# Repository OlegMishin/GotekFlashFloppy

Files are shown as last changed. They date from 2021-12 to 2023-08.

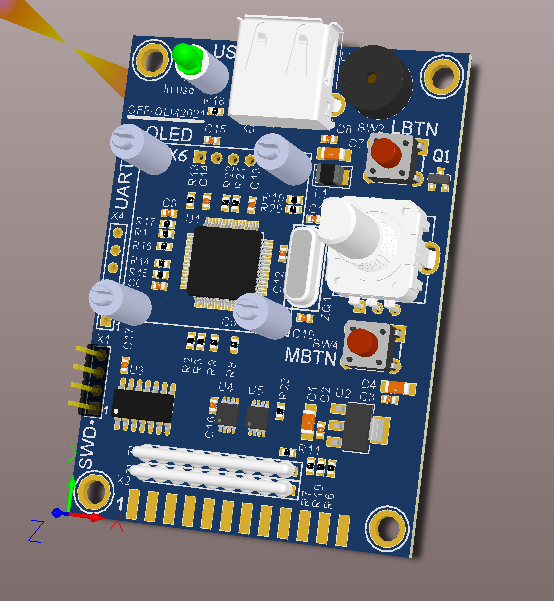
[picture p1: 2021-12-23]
gff-3D-render.png

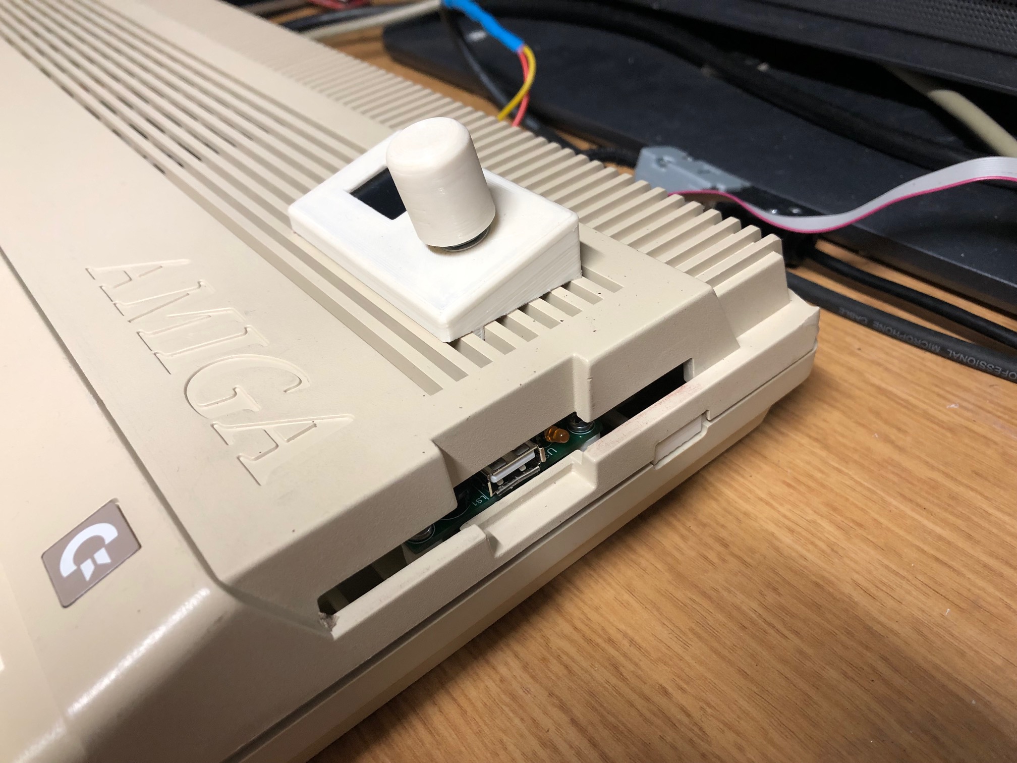
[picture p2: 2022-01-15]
A500_mount_example1.jpg

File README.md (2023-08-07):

# GotekFlashFloppy

A Gotek based PCB for Amiga computer. Can be mounted externally and internally.
Can be equipped with push buttons or with a rotary encoder. A 0.96" OLED display can be directly mounted using 4 spacers. I use 0.96 128x64 OLED (25.3x26.1mm overall dimensions) which is available in various online stores.

A 23-pin connector can be directly soldered to the pcb. Also, with an adapter pcb (23 to 34 pin) it can be mounted internally as "classic" Gotek pcb. 
Adapter's Gerbers located in **"gff_int_adapter_rev0.zip"** archive.

## Building

The BOM provided to build the drive as an external. Drive select configured as Drive 1 (selectable via R6/R7/R10).
The enclosure STL files also provided in "Cad\external case" location.
U4/U5 and the buttons unmounted. 
For louder movement sound I would recommend to use a MOSFET (e.g. IRLML2803 etc) instead of the BJT due to lower voltage drop.

## Firmware: 

Please refer to FlashFloppy's repository for the latest one: https://github.com/keirf/FlashFloppy

## MPU programming

Some early revisions of the MPU it can not be programmed via DFU. It is described in an application note AN2606(chapter 16.3.2):
https://www.st.com/resource/en/application_note/cd00167594-stm32-microcontroller-system-memory-boot-mode-stmicroelectronics.pdf

As I have such early revision of the MPU, I needed to use SWD interface. Actually, DFU mode flashing was not considered in the design. Related jumpers will be added in the next pcb revision.

Hardware: ST-LINK V2 (Chinese clone).
The MPU supplied from ST-LINK. It is enough for programming.



Software(Windows): STM32 ST-LINK Utility. Can be downloaded here: https://www.st.com/en/development-tools/stsw-link004.html

One important note to the ST-LINK flashing method. The following steps might be required if the MPU already programmed:
1. Run the tool, select "Connect under RESET" in settings. 
2. Connect ST-Link (it provides 3.3V which is enough for the MPU programming). 
3. Short C9 (to activate RESET)
4. Press "Connect" button, 
5. Release RESET
6. Open "hex" file and program it pressing "Program Verify" button.



Other HW tools can be used for the MPU programming:

- FT2232H based with OpenOCD. Very easy to build.
- J-LINK
- U-LINK

## PCB:

Two layers, 1.6mm thikness. Optimized for JLCpcb.

3D render of the pcb(Just a nice picture. Some components must be unpopulated):

изображение

Adapter board(soldered side by side to the main pcb):

изображение

## An example of internal mount with a 3D printed frame
Adapter's (frame) STL model is in CAD folder.

изображение

The display and rotary encoder mounted on top of the Amiga 500. Its model also in the "Cad" folder.
изображение

## As an external floppy
3D render.

изображение

The device in 3D printed enclosure. Connected to my Amiga 500
изображение

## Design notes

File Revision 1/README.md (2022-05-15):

# Revision 1

Changes list

- Removed U4/U5
- Updated Programming jumpers and related silcscreen
- Added +5V header to supply the board for MPU programming
- Added "Drive select" DIP switch. It planned to be accessible via an opening in an external enclosure
- PC mode (Jumper-C) is selectable via DIP switch

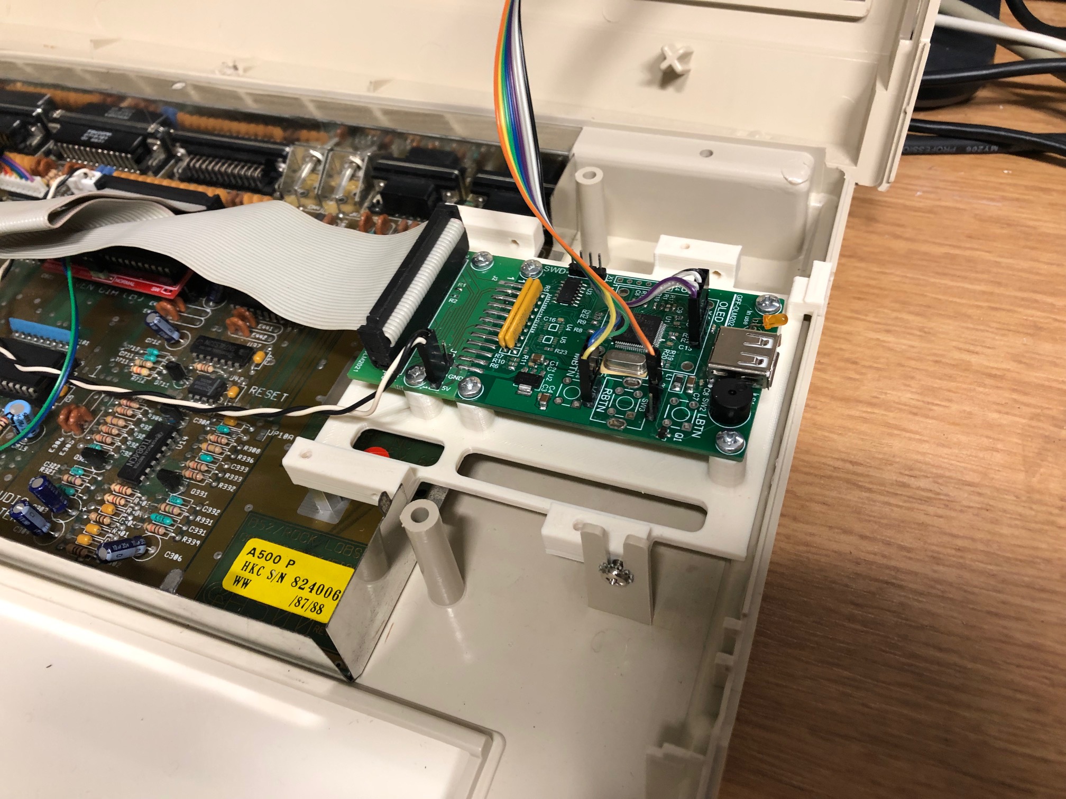
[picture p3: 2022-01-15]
A500_mount_example2.jpg

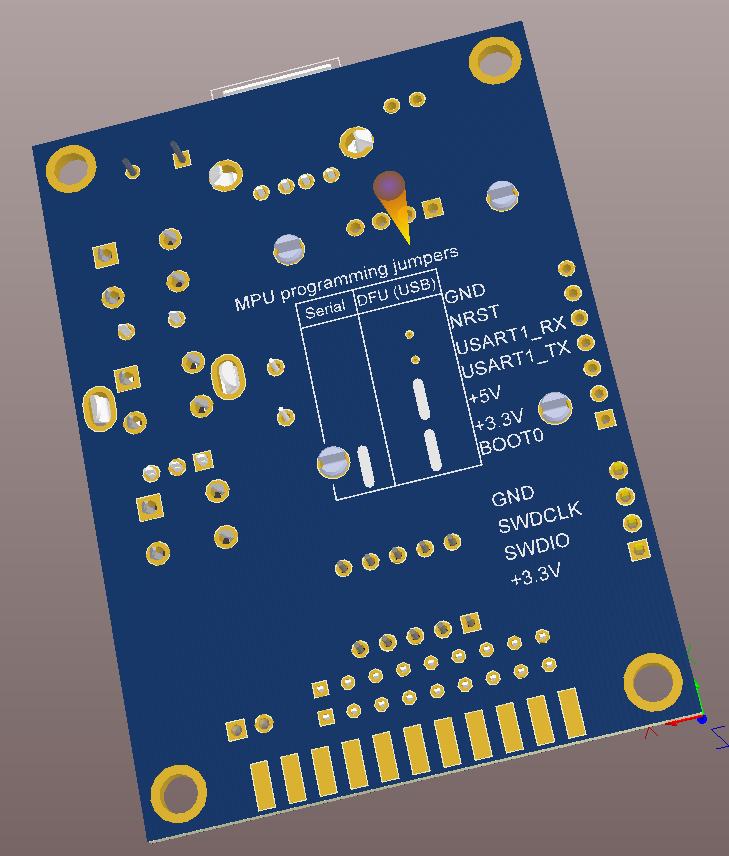
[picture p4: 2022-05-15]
Revision 1/3D_render_bot.png

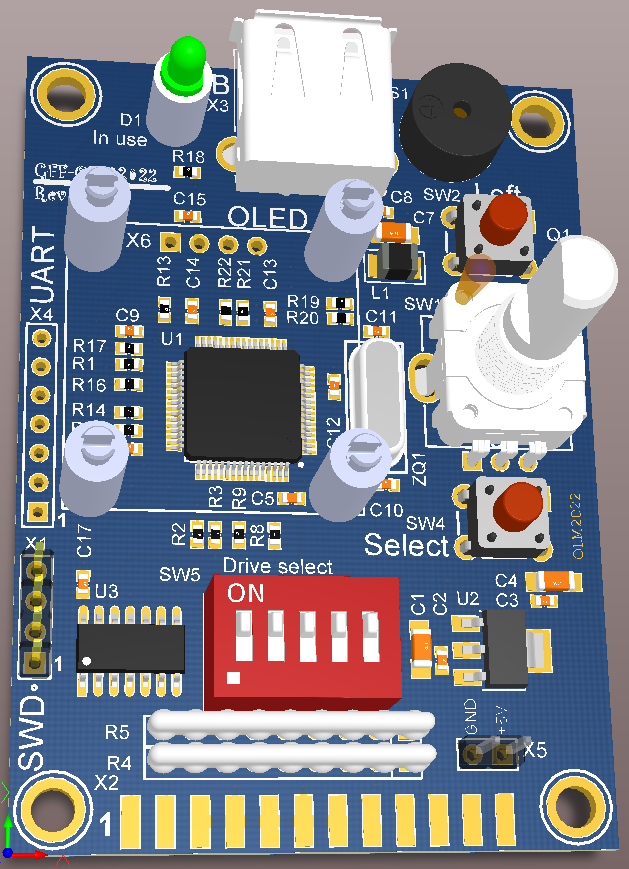
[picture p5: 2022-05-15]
Revision 1/3D_render_top.png

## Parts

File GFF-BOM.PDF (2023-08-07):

Designator | Quantity | Part | Description | Manufacturer | Comment | Value
C1, C4, C7 | 3 | C1206C106K4RACTU | Ceramic capacitor SMD | Kemet | Capacitor | 10uF
C2, C3, C5, C6, C8, C9, C12, C13, C14, C15, C16, C17 | 12 | CL10B104KB8NNNL | Ceramic capacitor SMD | Samsung | Capacitor | 100nF
C10, C11 | 2 | CC0603JPNPO9BN220 | Ceramic capacitor SMD | Yageo | Capacitor | 22pF
D1 | 1 | LED 3mm Orange | LED d3mm | | LED | d=3mm, Orange
H1 | 1 | 0.96 OLED I2C 25.3x26.1mm | 0.96 OLED display | | OLED display | 0.96 OLED I2C 25.3x26.1mm
L1 | 1 | BLM31PG601SN1L | Ferrite bead | Bourns | Ferrite bead | 600R @100MHz
LS1 | 1 | GT-0905A | 4-6V small buzzer (9mm) | Soberton | Buzzer passive | GT-0905A
Q1 | 1 | Alternative IRLML2803 | NPN Resistor-equipped Transistor | | Transistor | PDTC114ET
R1, R2, R3 | 3 | 10k 5% 0603 | Resistor SMD | | Resistor | 10K
R4, R5 | 2 | 4609X-101-102LF | SIP bussed resistor network. 8 resistors | Bourns | Resistor network | 1K x 8
R6, R8, R9, R16, R20, R21 | 6 | 0R 5% 0603 | Resistor SMD | | Resistor | 0R
R13 | 1 | 4.7k 5% 0603 | Resistor SMD | | Resistor | 4.7K
R14, R15 | 2 | 22R 5% 0603 | Resistor SMD | | Resistor | 22
R18 | 1 | 1k 5% 0603 | Resistor SMD | | Resistor | 1K
SW1 | 1 | PEC11R-4020K-S0024 | Rotary encoder with a switch | Bourns | Rotary encoder | PEC11R-4020K-S0024
U1 | 1 | STM32F105RBT6 | ST MCU with CAN and USB | ST Micro | Microcontroller | STM32F105RBT6
U2 | 1 | REG1117-3.3 | 800mA LDO Regulator | Texas Instruments | LDO | REG1117-3.3
U3 | 1 | SN74LS07DRE4 | Hex Buffer (Open Drain) | Texas Instruments | IC | SN74LS07DRE4
X1 | 1 | 5-146285-4 | SWD connector | TE Connectivity | Connector | PLS-4
X2 | 1 | DB-23 Male | Amiga external floppy connector. 23 pin Male. | | Connector | DB-23 Male
X3 | 1 | 292303-5 | Conn USB 2.0 Type A | TE Connectivity | Connector | 292303-5
X4 | 1 | 5-146285-6 | Header, 6-Pin | TE Connectivity | Connector | PLS-6
X6 | 1 | 801-87-004-10-001101 | Female Header, 4-Pin | Preci-Dip | Connector | BLS-4
ZQ1 | 1 | HC-49/U-S8000000ABJB | Crystal | Citizen Finedevice CCR YSTAL | | 8MHz

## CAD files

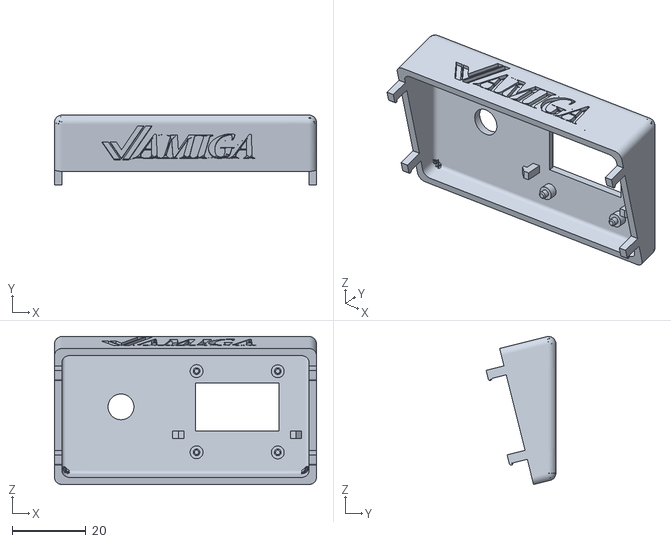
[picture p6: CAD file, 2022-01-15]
Cad/A500_rotary_128x64_oled_v20.STL
71.0 x 18.9 x 40.1

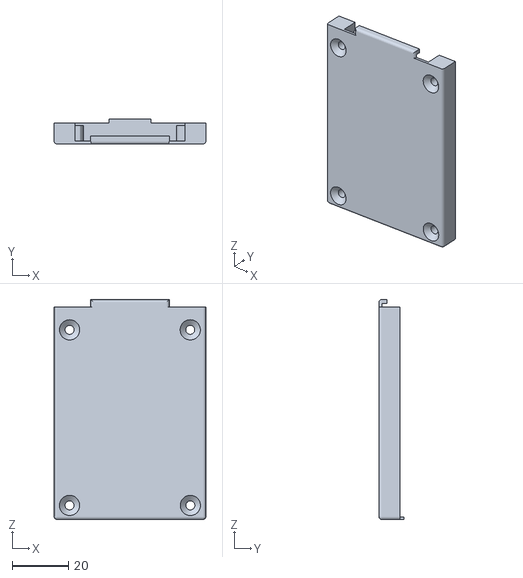
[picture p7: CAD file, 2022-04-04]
Cad/external case/Case_bottom.STL
54.0 x 8.90 x 78.3

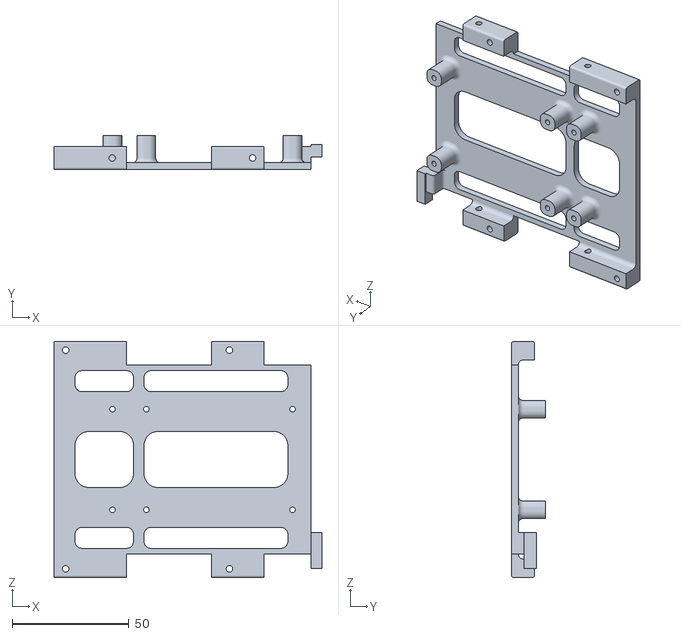
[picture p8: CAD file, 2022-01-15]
Cad/A500_internal_mount_v2.STL
114.6 x 14.7 x 101.0

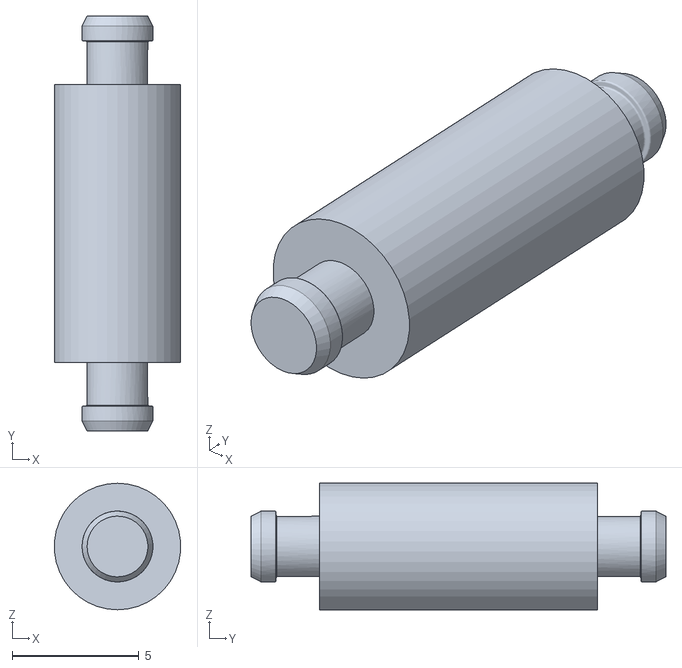
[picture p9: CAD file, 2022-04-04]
Cad/external case/Spacer_OLED.STL
4.98 x 16.4 x 5.00

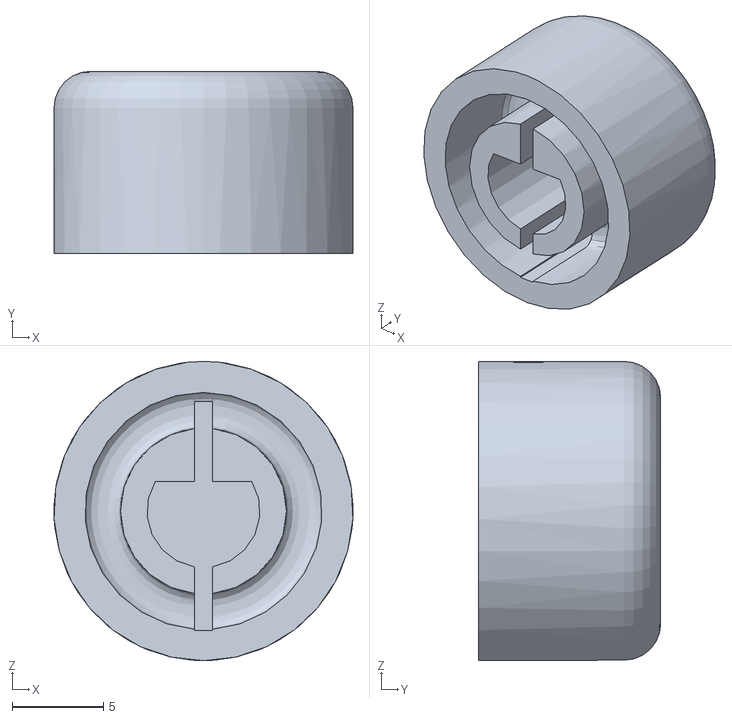
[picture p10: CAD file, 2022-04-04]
Cad/external case/A500_rotary_knob_H9.STL
16.4 x 10.0 x 16.4

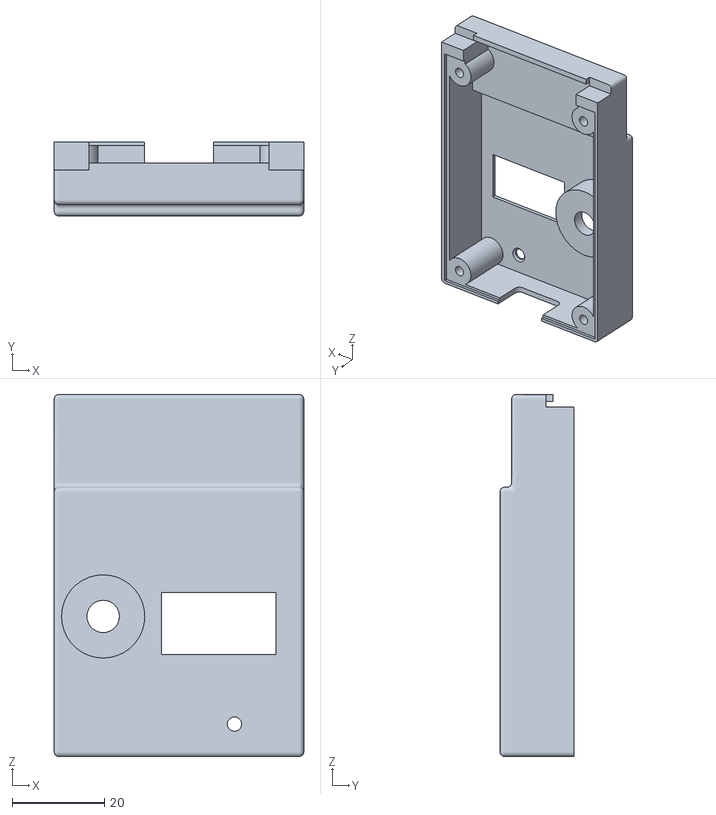
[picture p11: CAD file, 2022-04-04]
Cad/external case/Case_top.STL
54.0 x 16.0 x 78.3

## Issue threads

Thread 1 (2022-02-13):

BOM missing u4/u5

thbreidenbach, 2022-02-13:
Hey, wondered if missing u4/u5 is on purpose for maybe another hardware revision. I ordered them from the Schematics but since there's no design files it's also a bit hard to always find the right footprints for ICs. Maybe you could either give access to design files or add more information to the BOM.
Great work anyways!! Ordered 3 PCB and will give feedback!!

OlegMishin, 2022-02-13:
Hi,
U4/U5 are optional components to implement Amiga's external drive circuit(I've updated the schematics with such comment). As FlashFloppy supports this feature in firmware, U4/U5 are not needed. The  ICs and other components which shall be not mounted marked as DNP on the schematics.
Please follow the BOM for components ordering and assembly.

Thanks for your feedback!

BR
Oleg

Closed 2022-04-09.

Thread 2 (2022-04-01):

First populated Board not working

thbreidenbach, 2022-04-01:
Checked the board the whole day, no sign of life.
For programming you might consider making 5V accessible on e.g. the uart connector. For USB/serial programming access to 5V is necessary so placing it next to tx would be beneficial.
That said, also debug led might be handy when checking the board.

How did you program the board initially? Is there some clue since UART and USB give no response.
For UART I used 5V from the Drive Connector and connected rx/tx and vice versa and a jumper from Boot0 to 3.3V. No life..
For USB I connected TX/5V and Boot0/3.3V. No connection/Hardware detection possible.

Another question with regards to r4/r5: Are those networks bussed or star?

I'll add some Photos, maybe you can spot an error. For differing footprints I measured for connection. All fine
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
.

Thanks in Advance!!

Yours Thorsten

OlegMishin, 2022-04-02:
Hello Thorsten,

Thank you for building my board. The soldering looks very nice. I see no errors.
Regarding the MPU's programming. I program it via SWD interface (as you see, there is X1 connector mounted). I use ST-LINK v2 (cheap Chinese clone) debugger and STM32 ST-LINK Utility SW. Let me update "read.me" file with the short instruction.

Just checked my boards, the DFU mode did not work for me. There is an Errata item in MPU's datasheet, looks like it not possible for earlier releases of the MPU:
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
My MPU has "043" date code. Seems this is a problem. If I see correctly, on your MPU the date code starts from 4 - the same issue.

Regarding R4/R5 they are bussed according to Bourns description:
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
Please refer to the board's schematics:
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

Hope my answers help :)

Regards
Oleg

thbreidenbach, 2022-04-02:

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

OlegMishin, 2022-04-02:
Thanks for the feedback. The items go to a TODO list.
I have a question about Drive Select. As the selection already implemented via solder-jumpers R6/R7/R10 as on the below picture, do you mean it would be better to have normal jumpers instead?
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

thbreidenbach, 2022-04-02:
Hi, indeed solder jumpers are not ideal for an external drive which might easily be used in different systems. Indicator led would be fancy.

Yours
Thorsten

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

OlegMishin, 2022-04-04:
Hi,
Ok, I will consider at least jumpers or a DIP switch. So it would be possible to change the drive number and see the current configuration without opening the case. I will also update 3D model of the external case.

Regards
Oleg

thbreidenbach, 2022-04-04:
Perfect! Are files for the external case up yet? Would 5V be possible next to TX for chip revisions that offer usb programming? For uart 5V supply is also mandatory and unavailable as of yet. (Labels/Silkscreen would be important)
Yours
Thorsten

Von meinem iPhone gesendet

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

thbreidenbach, 2022-05-14:
Hey Oleg, I’m about to order several PCB. Have you had the opportunity to offer some production files? If possible I’ll test as soon as possible. The design looks extremely well.

There was one thing that came to my mind. I use a PC Bridgeboard which needs the JC jumper be set. Since the goldengate provides a db25 con that would be nice.

Hope you’re doing well, your Gotek still works like a charm! Thank you!

Thorsten

OlegMishin, 2022-05-15:
Hi Thorsten,

I'm doing well, thanks. Hope you too.

I'm happy the device is working well for you. Initially it was designed for Amiga use only, but recently I bought an old PC mainboard and started to play with DOS stuff, so it was very useful in a PC mode too. Due to this I added a JC to the DIP switch.
If the design looks ok for you, you can build it using the gerbers I put in "Release 1\gerbers" folder. DRC completed without any issues, so it is safe to build.

I didn't get you point regarding db25, what do you mean? Is it about some other computer connection, other than Amiga/PC?

BR
Oleg

thbreidenbach, 2022-05-15:
Hey Oleg, great News! Will order a bunch of ten immediately.

My point was that the Bridgeboard utilizes the same connection than the Amiga, so it’s an even greater addon with a jc jumper. Some PC Cards have a different external connector I believe and would need different interface. But this fits as is. This way I can use the internal Gotek in my Amiga 4000 as an Amiga Drive. Your board is perfectly fitted for my Big Box Amiga with Bridgeboard!

yours
Thorsten

Closed 2025-07-10.

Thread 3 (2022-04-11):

Need a fully assembled PCB

danko79, 2022-04-11:
Hi Oleg, i'm Juri from Italy, i find your project and really interesting, would you have an assembled PCB for sale?
sorry but i didn't know how to contact you.
Regards

OlegMishin, 2022-04-11:
Hi Juri, nice to meet you.

Sorry, I don't have assembled pcb for sale. At least for the revision 0. There are some upcoming changes towards revision 1, I'm going order some pcbs for testing and some of them perhaps will be available for sale. I will update the project's information here when it is ready but can not promise it will be soon.
Could you please have a look at the "Revision 1" files and let me know if you have any coments.

Thanks!

Regards
Oleg

Closed 2022-04-24.

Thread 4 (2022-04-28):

R1 & R2 internal connector PCB

drwhy75, 2022-04-28:
Hi !
Nice work !!
I am trying to build one of your Rev0 boards but I am not able to find the values for the Resistors R1 & R2 on the little
internal connector PCB. (could not find / or see them in the BoM).

So far I have finished soldering all components (without R1 & R1 & the buzzer).
... will try to flash the FW when all soldering is finished.

Cheerz

OlegMishin, 2022-04-28:
Hi!
Thanks! The resistors in fact are jumpers for drive selection. As you can see on the adaptor's schematics, R1 is 0R and R2 is DNP (Do Not Populate). This is a default configuration for drive 0(e.g. internal drive). R2 is for drive 1 configuration (R1 should be removed).

Regards
Oleg

drwhy75, 2022-04-28:
... ahhh ! Thank you !

drwhy75, 2022-04-28:
Hi !

Thank you for answering !

… another question:
What do you think about adding a second connector (DB23 female or just a pin-strip) to the board,
to pass through a 3rd and 4th drive, just like the real external amiga drives where built in the 90´s.

I don’t know if this is possible with the Gotek FW or what other things will be needed for this,
or if its even needed by the AmigaCommunit these days …

Best regards,
Wolfgang

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

OlegMishin, 2022-04-28:
Hi Wolfgang, you are welcome!

Honestly I did not consider to create something similar to usual Amiga's external drive. The goal of the project is to create a small external floppy emulator, directly plugged-in to the Amiga. I make the adapter pcb to place the device inside of Amiga to replace its internal drive.
Sure, it is possible to connect more than two Goteks with actual FW as the drive selection is a HW thing. There are plenty of old external drives available and my current Gotek+adapter can be installed into them with a 3D printed frame. But in this case it is cheaper to buy an original Gotek and put it into existing case.

Maybe makes sense to develop a classic external drive (with a pass-through connector) completely, including a 3D printed enclosure. But as I'm quite happy with the current one, it could be a long term plan :)

I'm currently collecting feedback for the current release and planning to release the next revision in future. Please have a look at "Revision 1" directory. It contains draft documents for the upcoming pcb.

Regards
Oleg

drwhy75, 2022-05-04:
... so ... my first board seems to work so far !
(but I did only some short tests, more coming when its really finished soldering !)

I am still waiting for my db23 Connectors and the PiezoBuzzers and, sure I have a wrong sized OLED display too,
so mine looks like that ;-)

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

but as I said before,
nice project, thank you !

Ah ! One more thing:
I tried to order the "drive-enclosure" via JLCPCB´s 3D printing service but after reviewing the
.STL files they send me an email with the info:

A500_rotary_OLED.STL, CASE_Bottom.STL & CASE_top.STL contains errors and bad edges !
Also the wall-thickness is too thin (only 1mm ... 1.5mm would be better, because of highly risk
of deformation and cracks.

best regards,
Wolfgang

OlegMishin, 2022-05-04:
Hi Wolfgang,

Thanks for your feedback and pictures. Looks very nice :)
I will update the wall thickness to match Jlcpcb requirements.

Regards
Oleg

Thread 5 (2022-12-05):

Rotary Encoder weird working

nosyn00b, 2022-12-05:
Hi Oleg,
   I successfully assembled your version of Gotek Flash Floppy with great satisfaction. I assembled it from scratch using the old PCB revision - the one without dip switches - because I had just ordered the old PCBs version when you uploaded the new one :-(.

Thanks for your excellent work, after some issues with an Amiga/PC modified drive, that caused all attempt to read an ADF fail even if I could see all files, I finally saw this little miracle working "simply" unplugging the internal drive (in this way I discovered what I purchased some months ago :-)).

But I have a weird problem with the rotary encoder: to make it "work" I had to use "rotary=buttons, half" or(!) "rotary=half, v2" options parameter in the FF.CFG file. Still, after playing with all parameters, I can only proceed forward in the menu items, there is no way to go backward. I checked the PCB tracks for shorts one million time but it's all as it should be according to the schematics. Do you have any suggestion to try solving this (apart purchasing and trying with a different encoder). Do you know if it makes sense to change some other parameter (eg the default twobutton-action=zero). Or perhaps, this is the "by design" behavior with your Gotek version?

Thanks for your support.

nosyn00b, 2022-12-05:
I used a cheap chinese one [here](https://www.aliexpress.com/item/4000285265971.html), but I did not have any problem with other similar projects with the sibling rotary encoders I purchased in the set.

If you did not have problems with the default settings, I definetly suspect the single one I used to be defective... will try with another one, and check if something changes before going with an expensive Bourn :)

I'll let you know. Thanks really much for your really quick answer!

nosyn00b, 2023-01-10:
Hi Oleg, I confirm the problem was a false contact on the microprocessor pin. When testing I inconsciously pressed a bit the pin and so it made contact, but when not pressed the contact was no more there. Sorry for disturbing you with this issue. Now the standard encorder works flowlessly.

Closed 2023-01-10.

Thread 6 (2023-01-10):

Weird behavior when used as DF1:

nosyn00b, 2023-01-10:
Hi Oleg,
  finally I have mounted a new DF0 floppy, because the old one had not a true ready signal and the hack made a mess, causing the Gotek not to work (typical DF1:???) . Now that I have definitly solved the issue with the internal drive hack I can use your gotek both as a df0 (forcing it as "bootable df1" with my ACA 500), and as df1, in combination with the real df0.

Anyway, when using he real df0 drive and the Gotek drive as df1, I discovered that insertion/change of a disk in the Gotek drive are acknowledged only if the Amiga boots with a disk already inserted from the start. If I boot with a "disk ejected" status on the Gotek, there is no way to make any disk visible/functioning in a second moment: the Gotek floppy in this case stays steadly on track 0 after disk insertion... no way to change that.

Perhaps this is not an obvious misbehavior, because to have a disk in ejected status from the start you have to configure the gotek to do so (for me is very logical to start  without a disk already interted, so I configured the Gotek in that way). Do you think this is caused by the FlashFloppy software, or has something to do with the hardware? I suspect that absence of the motor on logics/chips (optional an untested, right?) could have some influence on that, but its only my supposition.

What you think about that? Can you reproduce the same behavior or is something wrong with my gotek?

OlegMishin, 2023-01-14:
Hi,
By chance I have never used my gotek as an external drive without a disk in it. So the issue was not observed.
Truing to reproduce such behavior I did confirm that if i did not insert USB stick and start Workbench, the drive was not detected by system. If I used normal external floppy, booting without any disk in it, the floppy drive was detected by system an reacted on disk insertion. I would assume, it is correct behavior.
Yo are right about optional U4/U5 chips. It is a circuit from real external drive.  It was implemented just in case and was not tested. I checked today and do confirm - with these components, my gotek was detected by system even without USB stick inserted. But if you want to mount them be careful, there is a bug in the circuit. Pins 1,2 of U5 shell be connected to "A-SEL1n" (or 2, 3), not to "A-DIR".

Here is the PCB's mod:
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

nosyn00b, 2023-03-16:
Only to let you know that (while searching and finally now waiting) for required components, I had a better read through Keirf documentation about FlashFloppy (FF) and specifically about [Amiga hints](https://github.com/keirf/flashfloppy/wiki/Host-Platforms#commodore-amiga)

From what I understand the behavior is standard with the current FF firmware, and it should be common to  any Gotek without flip-flop circuitry (not only yours when U4 and U5are not installed).

This happens because when the standard “shugart interface mode" is configured, the FF do not send any "Drive ID" on the Ready signal, when motor is off, but simply asserts READY whenever a disk is inserted regardless of the motor on/off state. So this “disk insertion Ready" assertion works as Ready signal when motor is on, and also a a DD “Drive ID-sequence” in case the moto is off.

This works perfectly when the Gotek is DF0, but when it is used as DF1 with a "passive interface cable" (eg no external enclosure and flip flop motor logic), and the FlashFloppy is configured to eject-at-power-on, or has no USB stick inserted or simply it’s too slow to initialize, then RDY in not asserted during boot when the motor of external drives is enabled and the drive is not managed as it should.
The good news is that you can “solve” this problem configuring Gotech with the interface = amiga option.
In this case the Ready/Drive ID signal is managed differently from the FF: the Drive ID sequence is constantly sent on the READY pin and makes his work when the motor is off. Because the Binary sequence simulates a Ready signal it also works when the motor is on, so the drives works as expected during boot even if the floppy disk is not inserted from the start.

I tested this configuration and it seems to work even with the “basic” variation.

OlegMishin, 2023-03-18:
Thank you very much for your finding!
As usual - RTFM :) and I had no time for that :)

Closed 2023-03-18.

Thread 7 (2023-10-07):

Setup Rev.1 Question

venice1200, 2023-10-07:
Hi,
this is not an issue, more a question how to setup the board for df1 usage.

I got a Rev.1 PCB assembled and FlashFloppy 3.41 installed.
Display, USB and Rotary are working but the board is not detected by my Amiga 500.

Do I only need to close the „jumper“ for drive 1 to activate the board for df1?

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

Many thanks for this compact Gotek Drive.

venice1200, 2023-10-07:
Full Board View

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

OlegMishin, 2023-10-08:
Hi,
Correct, only DIP "1" shall be ON for Amiga's Drive 1. If there is no issues in soldering it should work. I would recommend to clean the pcb with isopropanol. It looks a bit dirty.

venice1200, 2023-10-13:
It looks like cleaning does the job as I don't find anything wrong.

But is it correct that the LED is slightly blinking all the time even the drive is not accessed?

See:

https://github.com/OlegMishin/GotekFlashFloppy/assets/43762187/e5c33d22-e26a-4733-8af2-41b048c1ded9

OlegMishin, 2023-10-16:
I see the same blinking in my boards but only when Kickstart is about to boot from it. After loading, e.g. AmigaTestKit, no more blinking.

venice1200, 2023-10-16:
The blinking is controlled by the MCU or by the Amiga or from both together?

opengiveback, 2023-10-19:
Hi, congratulations on this great de:sign, and thank you for making it opensource.

I made Revision 1 boards also, and have one assembled and working, but also have a question. Is it possible to use the "Revision 1" PCB based device as DF0: ? I have used a normal gotek before, flashed with FlashFloppy and with an external gotek adapter, and when I set jumper S1, it was DF1:, when I set S0 instead, it became DF0: when I unplug internal floppy, on the external port also.

But **these dip switches start with 1? When I set "1" as on, it acts as DF1: , so how would I get this to be DF0: ?** When the internal drive is not connected, of course.

P.S. I intend to build more and also sell these, and give back 15% of profits to the author(s of hardware and software), as per my opengiveback.org idea. I believe everyone should give back to the authors of products built for sale from open source, so if you have any email for paypal donations, or other means of donating to you preferred by you, please let me know.

venice1200, 2023-10-19:
From my Amiga understanding you can use DF0 only internally without any modification's.

Means, you need the Rev.0 Adapter PCB and set it to Drive 0 to use it internally as DF0, if the Adapter can work with Rev.1. The Board himself should be configurred as Drive 1.

If you want to use DF0 externally you need a switch (Boot selector) which swaps the drive enable signals between DF0 and DF1.

If I am wrong correct me please.

venice1200, 2023-10-19:
Oleg, my issue is solved, feel free to close it.

Closed 2023-10-19.

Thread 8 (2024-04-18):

Problems with external version

CultiMAN, 2024-04-18:
Hi Oleg
Thx for a great project.
I have built some of your Goteks. I've always gotten them to work fine for the internal mount.
But now i have tried your external version and I get no active display or activity on the drive.
I'm using your DF0 DF1 switcher and that works fine, but the gotek itself is just dead (tried two)
I see 5 volt on the 5v pins and also 3.3 volt on the display. Is there anything i'm missing to get it to work externally?
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

OlegMishin, 2024-04-19:
Hi @CultiMAN,
In some boards I had a similar issue. I could flash the MPU via SWD but no startup.  It is related to BOOT0 state at power on. Try to add a 10k resistor between BOOT0 pin at X4 and GND.
Regards
Oleg

CultiMAN, 2024-04-19:
Ok thx. I will certainly try that and get back to you if it worked. I am travelling for work so will test next week.

sbambach, 2024-04-21:
Had same issue... Randomly it booted / or not ;-) 10k pulldown for BOOT0 fixed it.

CultiMAN, 2024-05-01:
Perfect that 10k fix worked! Now though i have another issue. Games work fine when booting from the external Gotek using the adf files already assigned on the usb stick. But when i boot into track 0 to use the menu
to select more disks i get the error below
.. Is that something you have seen on the external version? Tried two different usb sticks....
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

OlegMishin, 2024-05-02:
Sorry, no idea. Never had this issue.
Could you please describe step-by-step how to reproduce it?

CultiMAN, 2024-05-02:
Hi Oleg,
Sure - here is my setup.
1) I use your DF0-DF1 switcher.
2) Switch to use DF1 as boot device.
3) Use the above Gotek (the pictures) connected to the Disk Drive connector.
4) All the game ADF's work fine.
5) BUT when I go to the FlashFloppy menu (ID 0) - I get the error message - so I cannot get to the menu to add game disks to the Gotek. I will try another Gotek build later, to see if I've made some kind of soldering error.

OlegMishin, 2024-05-02:
I got it. The issue is related to "flashfloppy-hxc-file-selector" which I have never used. Usually I just copy ADF files to USB stick and use the knob for navigation.
If I have time I will check how it works with "flashfloppy-hxc-file-selector" and come back.

CultiMAN, 2024-05-02:
An update:
Tried the newest experimental version of FlashFloppy 4.6a. The release notes mentions this error was fixed. But the problem is still the same... I did not fix the issue

OlegMishin, 2025-07-10:
In my understanding it is a software issue, I can't do anything here. It was reported that the last working firmware is 3.29. Maybe a downgrade is the only option for now.

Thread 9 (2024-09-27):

Idea for new version

Vanles, 2024-09-27:
Hello,
very nice drive, I like it a lot.

Would it also be possible to install a "5-way switch"? I would really like that and it would look even nicer in terms of design, especially as an external drive. Perhaps it will be possible to take this into account in a new version and install the appropriate soldering points.

Like this one
https://t.ly/8tBXI

Thanks Marco

OlegMishin, 2024-09-27:
Hi Marco,
Thank you for the idea. Typically I use either buttons or an encoder(my favorite) in the Gotek, but can't imagine how to use 5-way switch. To change floppy images only two buttons are needed plus optionally third - "OK".
I wonder, does FlashFloppy SW support 5-way switch?

From design stand point, a low-height encoder's knob also looks good :)

~Oleg

Vanles, 2024-10-22:
Hello,

I think the stick is better than the rotary knob, that's why I asked.

Hi Oleg,

You could connect left to bottom and right to top and press the selection. That would work well in terms of control.
It would look great. Maybe you can find a solution so that you could also install the stick.

Maybe even more holes? :)

You could add an "Interactive HTML BOM", the plugin is available for many programs like Egel or KiCat... this makes the assembly easier :)

You're doing a good job with the platinum, I'll be making a donation in the next few days.

Thanks
Marco

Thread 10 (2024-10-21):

How to solder the external board to main pcb?

BitsRetro, 2024-10-21:
Hi there,

Thank you very much for your design and sharing. It's great!
The only question is that how do I solder the main pcb to the external board? It seems difficult to solder them together. Thank you!

OlegMishin, 2024-10-21:
Hi,
Right, there is a distance from traces to pcb edge due to requirement from pcb manufacturer. This is why its difficult to solder.
I usually cut a bit from mating pcb edges with sand paper or a file to remove the gap. Then it is easy to solder.

//Oleg

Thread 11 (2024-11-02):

Create iBOM?

Vanles, 2024-11-02:
Hello,

First of all, thank you for the great project.

Would it be possible for you to create an iBOM from the board?
This helps a lot when populating the board and can be used by most PCB programs. It's a small plugin.

https://github.com/openscopeproject/InteractiveHtmlBom

In KiCad, for example, it can be installed directly as a plugin. It then creates an inactive BOM HTML file.

That would be great :)

Thanks
Marco

OlegMishin, 2024-11-06:
Hi Marco,
Thank you for your comment and the suggestion. I will consider if it is possible creating iBOM for my other projects :)
I use Altium Designer, let me check what is possible there.

Anyway, at the moment, I don't plan to come back to this project.

Br
Oleg

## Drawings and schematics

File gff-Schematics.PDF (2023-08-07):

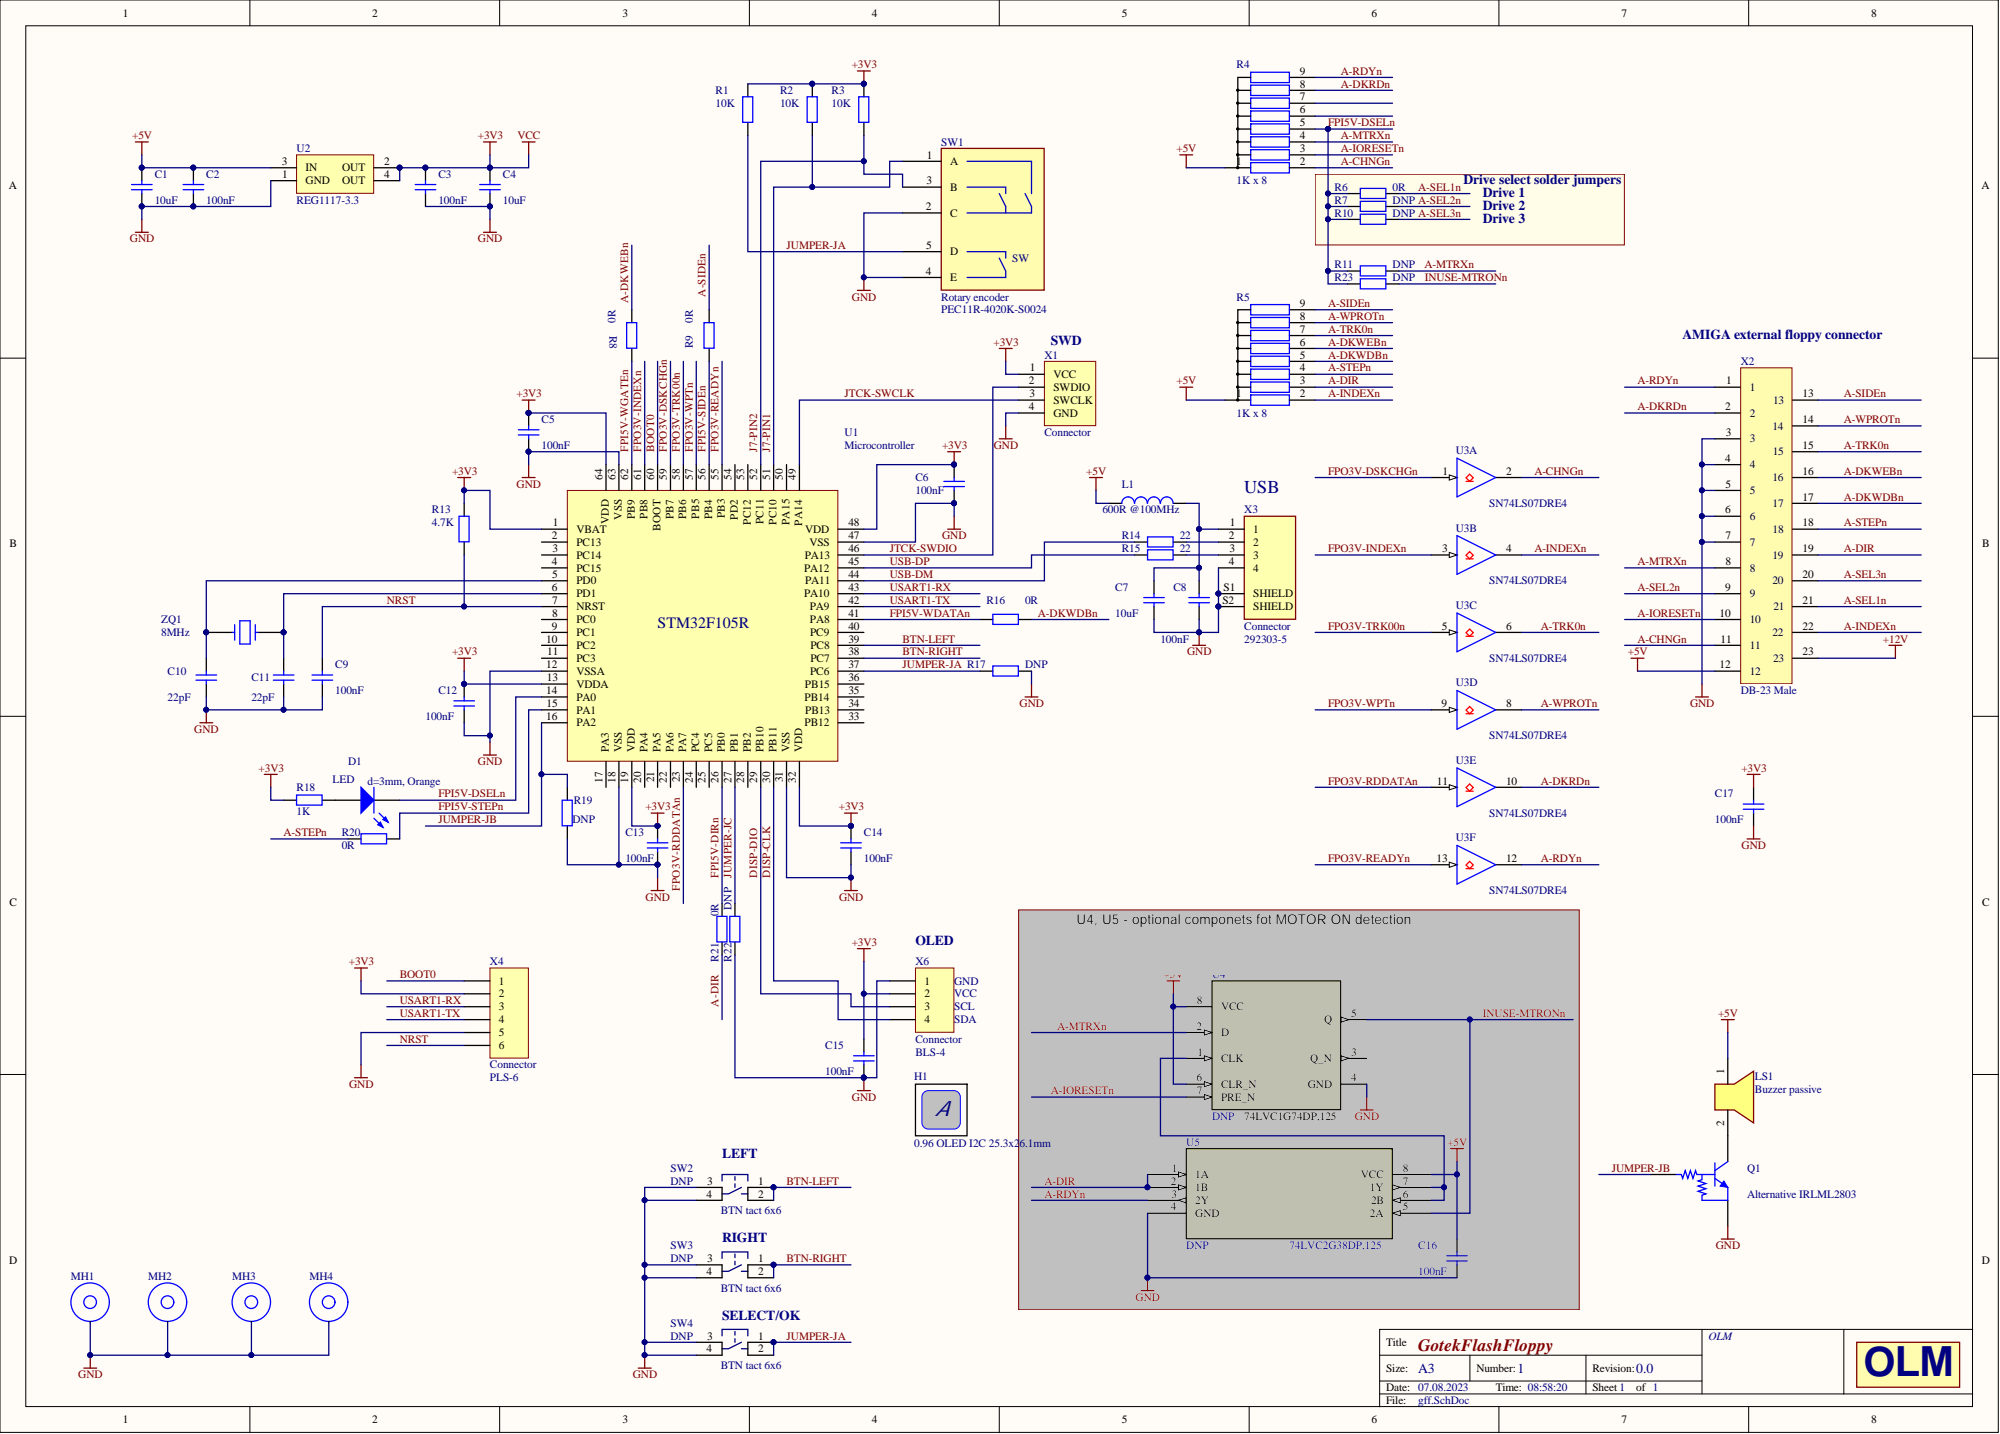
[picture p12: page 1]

Drive select solder jumpers Drive 1

JUMPER-JA | C 2

R7 | DNP A-SEL2n
R10 | DNP A-SEL3n

AMIGA external floppy connector SWD

PD1 6 | USART1-TX R16 0R

VSSA 12
VDDA 13
PA0 14
PA1 15

FPI5V-STEPn JUMPER-JB

U4, U5 - optional componets fot MOTOR ON detection

CLR_N 6

A-DIR | 1B 2

Title GotekFlashFloppy | OLM

Size: | Number: 1 | Revision: 0.0
Date: 07.08.2023 Time: 08:58:20 | | Sheet 1 of 1

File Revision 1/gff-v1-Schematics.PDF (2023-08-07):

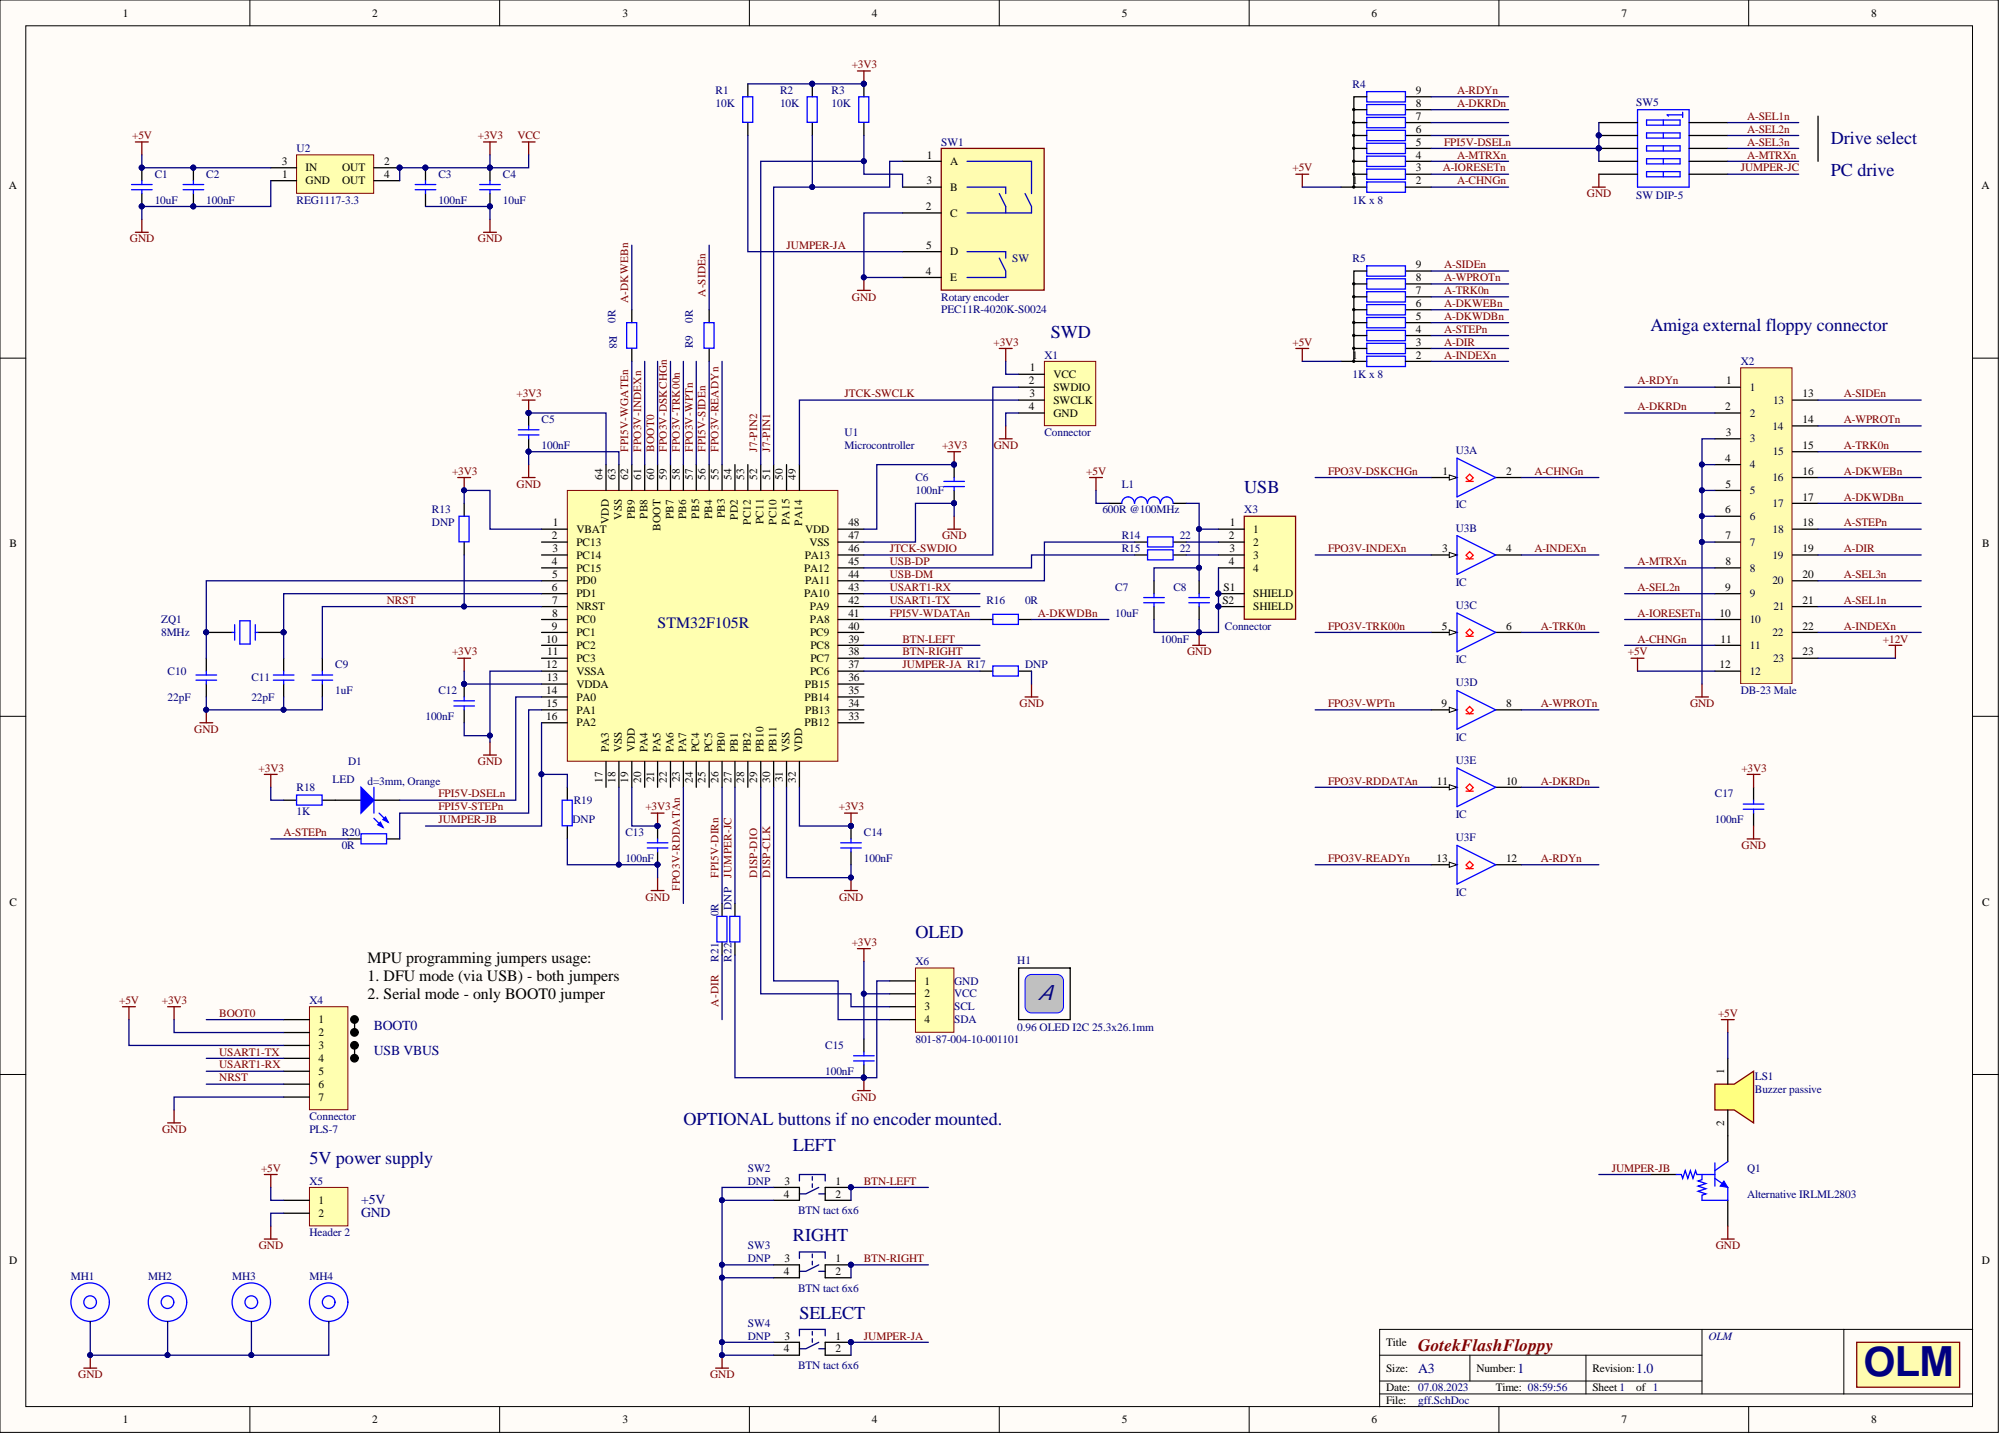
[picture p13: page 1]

6 5 | FPI5V-DSELn

JUMPER-JA | C 2

PD1 6 | USART1-TX R16 0R

NRST | | NRST 7 | SHIELD S2

VSSA 12
VDDA 13
PA0 14
PA1 15

FPI5V-STEPn JUMPER-JB

MPU programming jumpers usage:
1. DFU mode (via USB) - both jumpers
2. Serial mode - only BOOT0 jumper

OPTIONAL buttons if no encoder mounted.

Title GotekFlashFloppy | OLM

Size: | Number: 1 | Revision: 1.0
Date: 07.08.2023 Time: 08:59:56 | | Sheet 1 of 1

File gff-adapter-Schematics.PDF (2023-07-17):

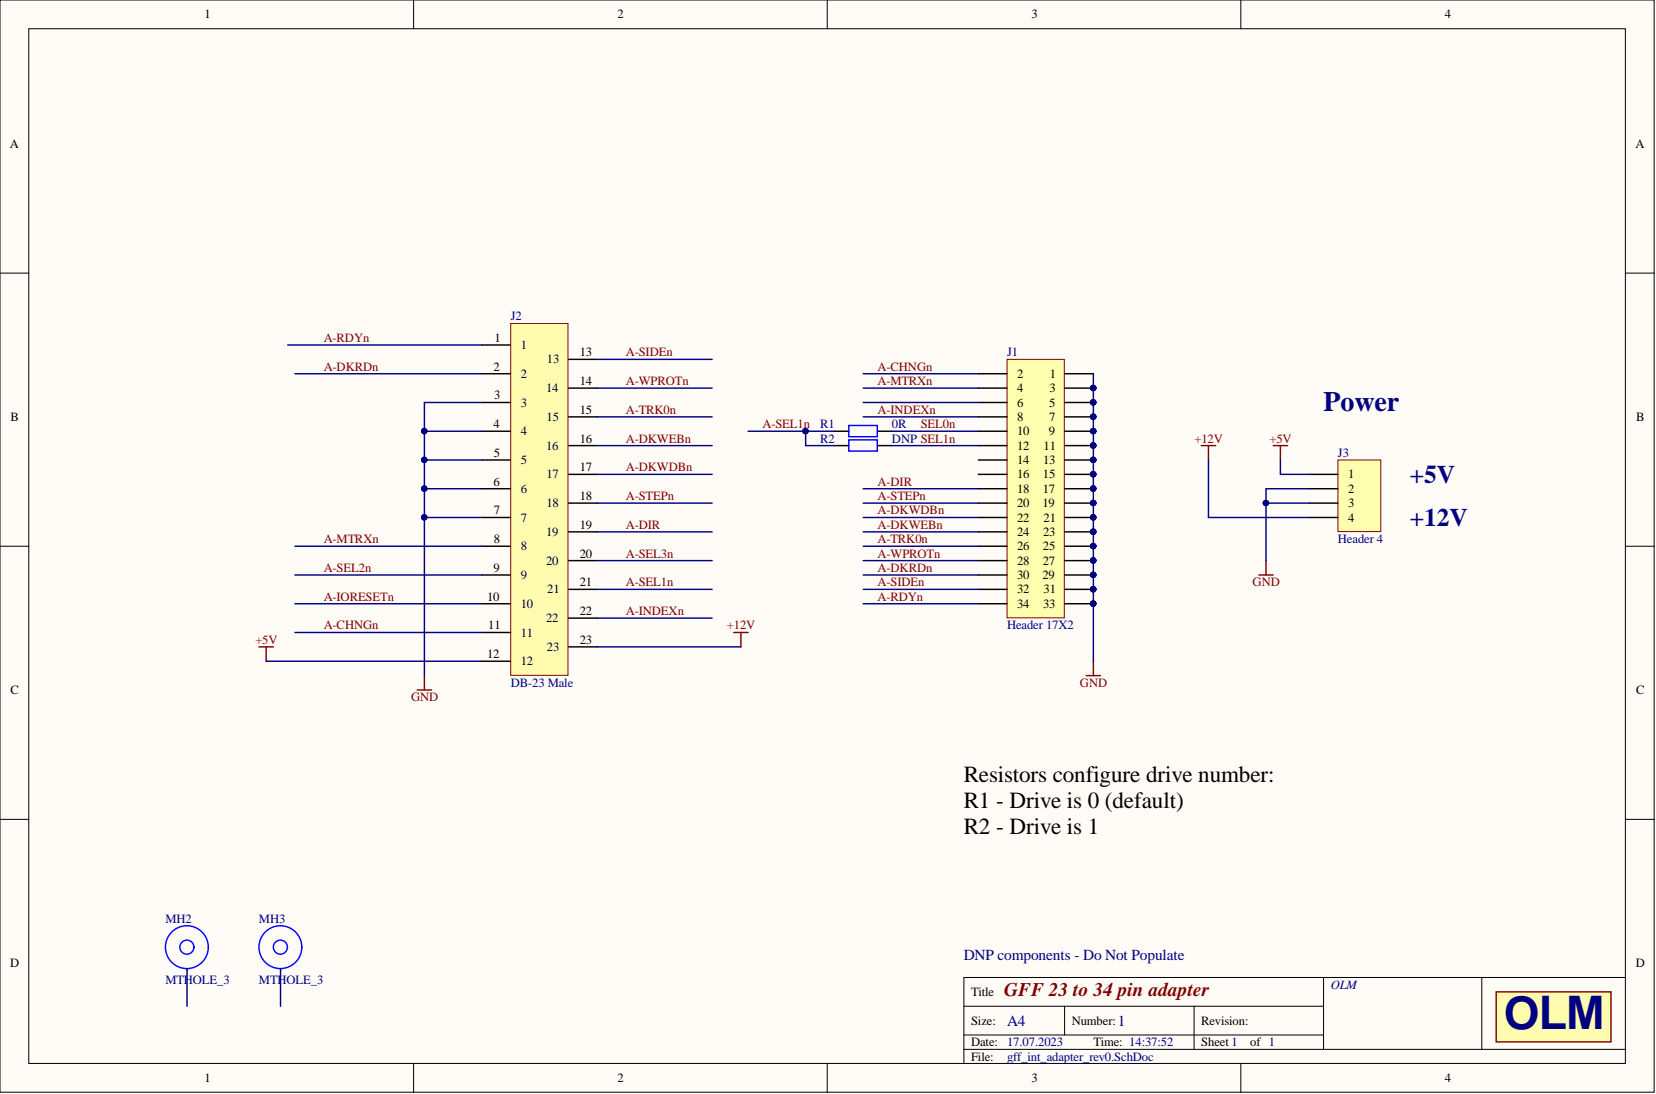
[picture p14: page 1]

T i tle | OLM

Siz e : A 4 | Numbe r : | Revis ion :

Dat e : T i m e : | | She e t 1 o f 1

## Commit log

2021-12-23 An initial commit
    [gff-Bill of Materials.xls]
2021-12-23 Add adapter pcb Gerbers
2022-01-15 Mount added
    [A500_internal_mount_v2.STL]
2022-02-13 Updted schematics(U4/U5 comment)
2022-04-02 Some tide up
    Schematic and BOM tide up
    [gff-Bill of Materials.xls]
2022-04-04 External enclosure files added
    [A500_rotary_knob_H9.STL, Case_bottom.STL, Case_top.STL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]
2022-04-04 Initial rev. 1 schematic upload
2022-05-15 The first gerbers release for rev 1
2022-11-13 Updated RESET circuit for better startup
2023-08-06 Update GFF-v1-BOM.PDF
    Fixed C10, C11 part number to match 0603 footprint
2023-08-07 Schematics/BOM update
